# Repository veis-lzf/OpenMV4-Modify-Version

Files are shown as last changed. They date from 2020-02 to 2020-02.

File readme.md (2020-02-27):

# Open MV 4修改版

- 说明：参考自官方设计，主要修改的内容如下

	- ① PCB层数由4层板改为2层
	- ② TF卡改为了自弹式卡坐
	- ③ 摄像头连接座子改成了和OpenMV3一样的OV7725摄像头模组（感光芯片+镜头）

- 官方开源设计链接：https://github.com/openmv

- EDA设计软件：Altium Designer 20

- PCB视图

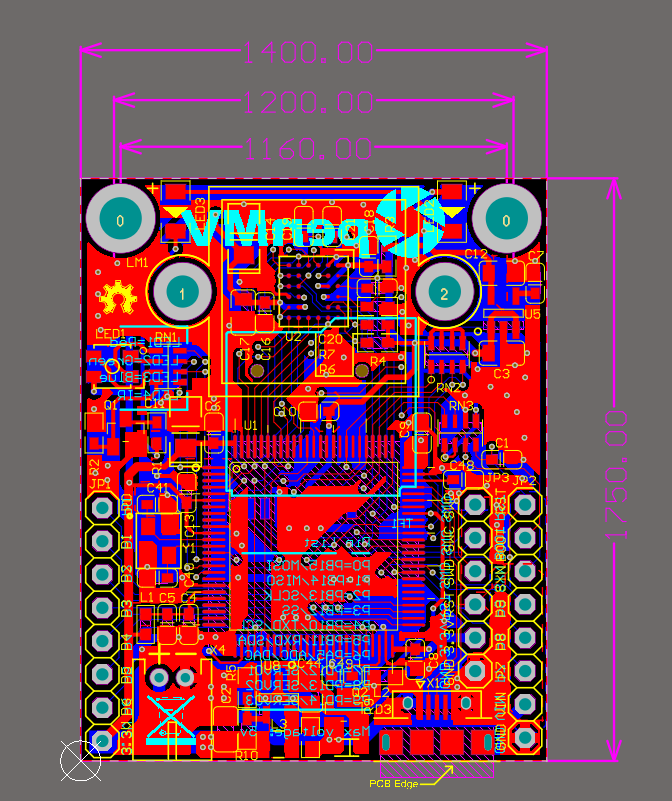
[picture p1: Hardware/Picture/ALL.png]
PCB-ALL
	

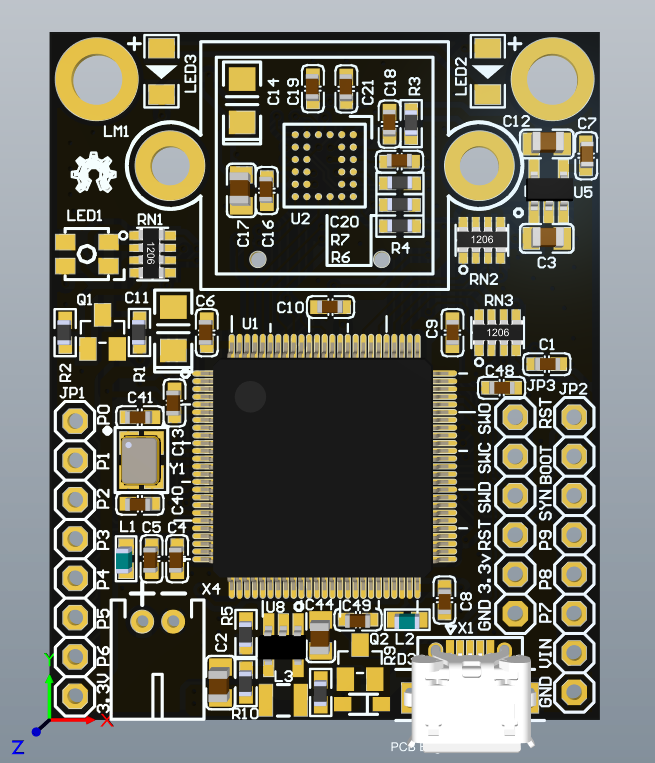
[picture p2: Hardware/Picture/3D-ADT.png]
ADT-3D
	

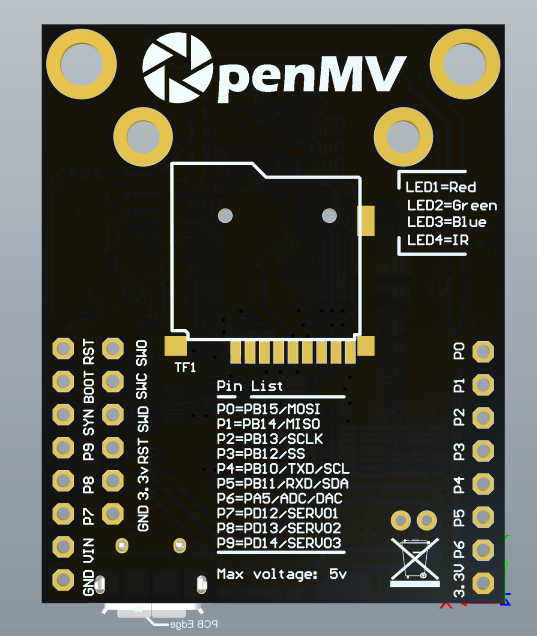
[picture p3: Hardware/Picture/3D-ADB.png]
ADB-3D


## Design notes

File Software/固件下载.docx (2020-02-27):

### 固件下载

官方固件下载： https://github.com/openmv/openmv/releases

中国服务器下载：http://openmv.cc/downloads/

参考资料：https://github.com/openmv/openmv/wiki/Using-DFU-to-update-your-firmware

DFU方式烧录固件（以OpenMV3为例）

1.安装软件

下载参考地址：https://stmicroelectronics-dfuse.updatestar.com/en

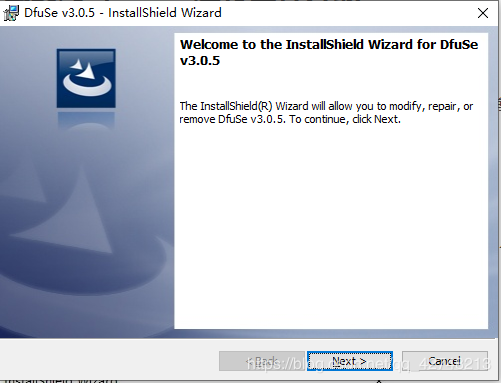
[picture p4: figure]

按照软件下一步点击即可完成软件的安装

2.进入DFU模式

用杜邦线连接Boot引脚和RST引脚。

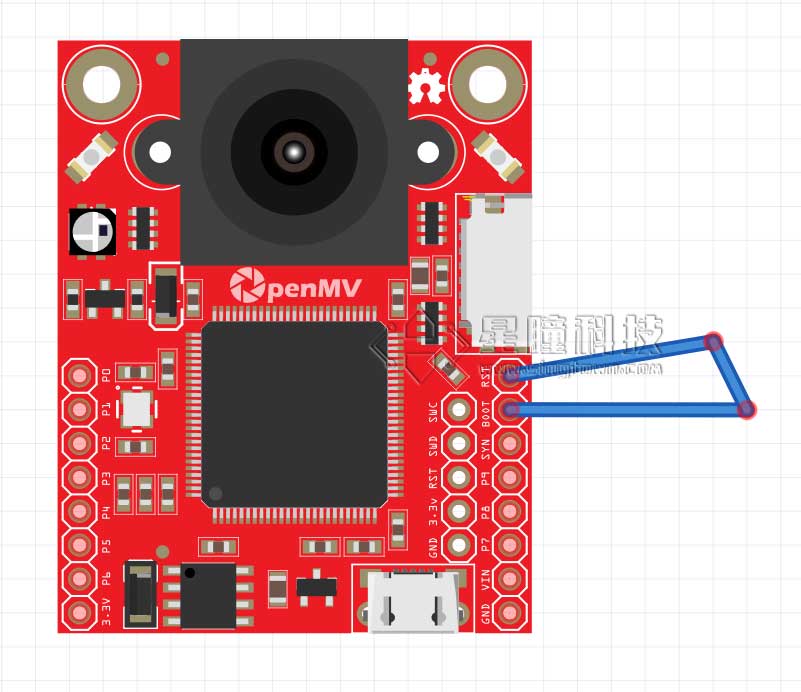
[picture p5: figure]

用USB先连接电脑后， 设备管理器会出现一个DFU设备

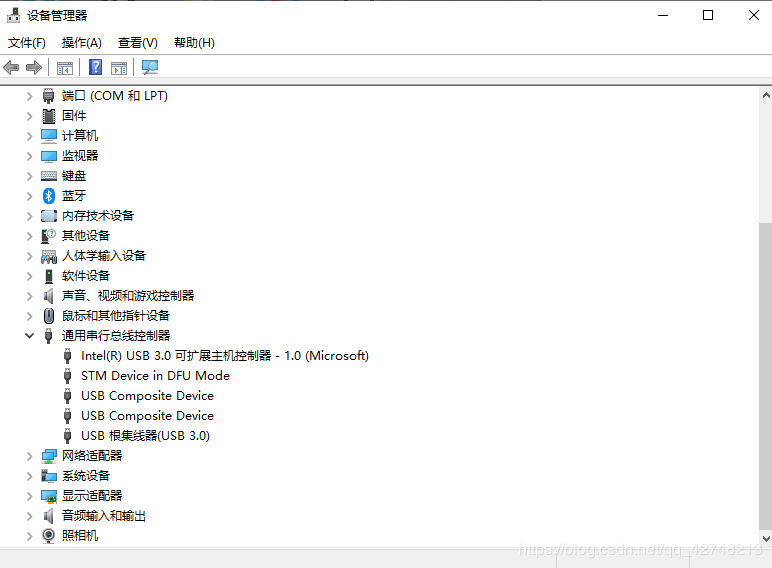
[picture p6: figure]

如果没有自动安装驱动，可以在DfuSe软件的安装路径中找到驱动文件，安装即可。

3.上传固件

打开软件，点击Choose选择openmv.dfu（不要选择左侧的Choose）

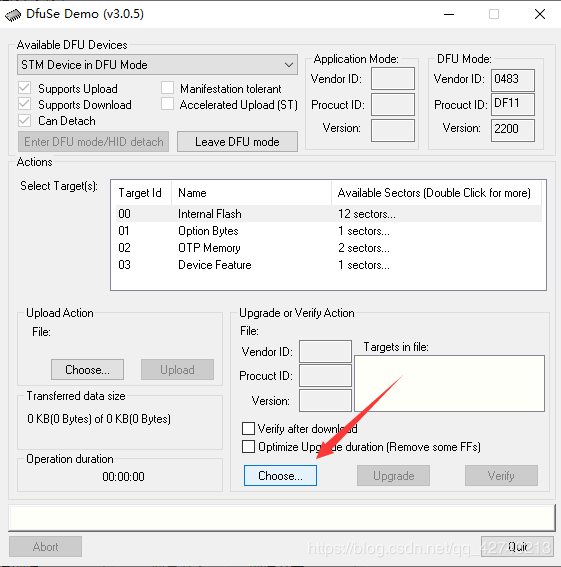
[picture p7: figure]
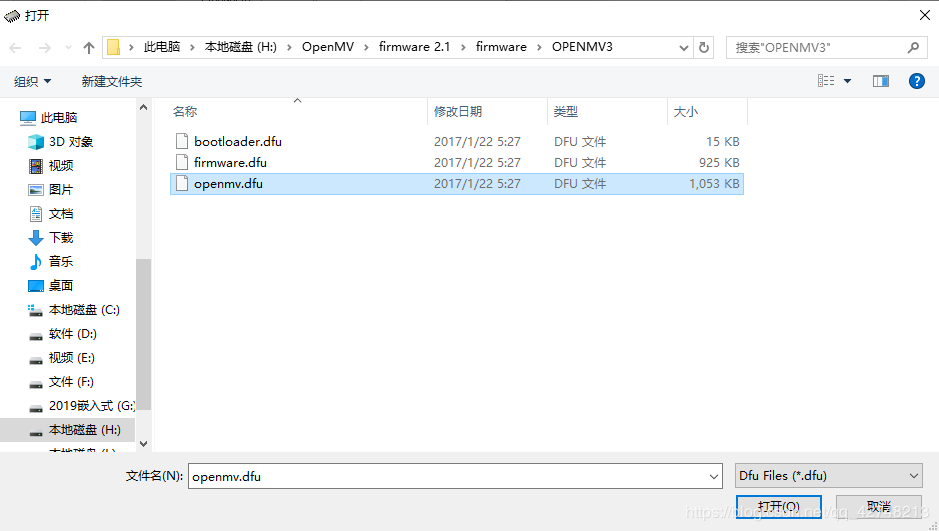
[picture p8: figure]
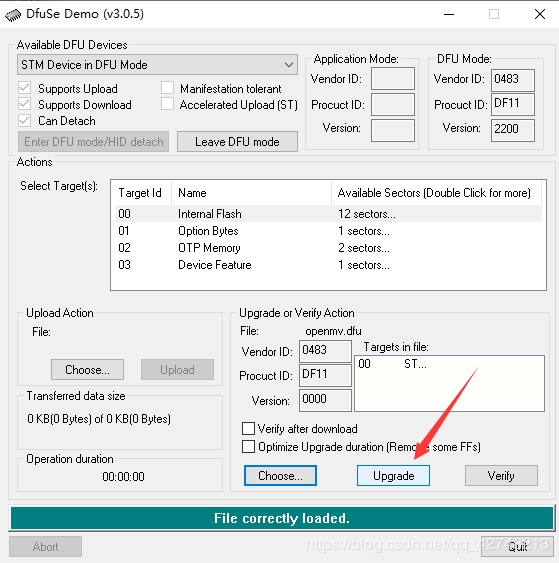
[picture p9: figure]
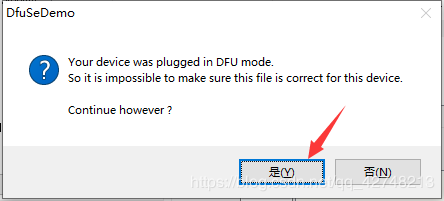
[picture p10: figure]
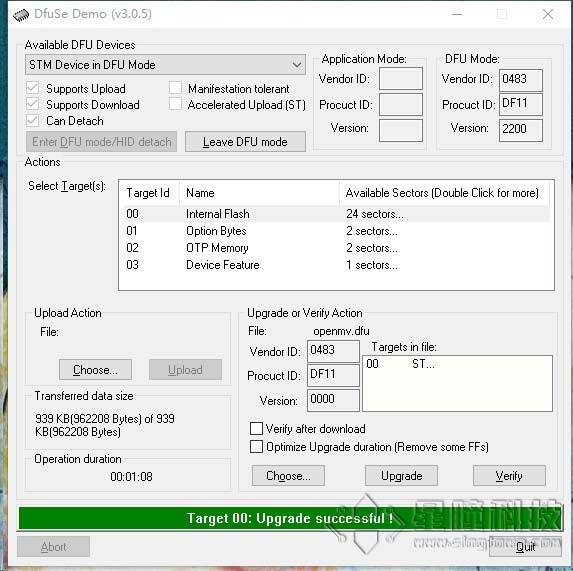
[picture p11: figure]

这样就上传成功啦。 拔下杜邦线，然后重新插上USB线，运行IDE试试吧！

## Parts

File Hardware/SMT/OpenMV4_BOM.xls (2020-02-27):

Comment | Description | Designator | Footprint | LibRef | Quantity
NC |  |  | OMV-LOGO-BIG |  | 1
NC |  |  | OSHW_FILLX100_NOTEXT |  | 1
NC |  |  | WEEE |  | 1
1uF | CapacitorStandard 0603 ceramic capacitor, and 0.1" leaded capacitor. | C1, C4 | C0603 | CAP0603-CAP | 2
22uF | CapacitorStandard 0603 ceramic capacitor, and 0.1" leaded capacitor. | C2, C17, C44 | C0805 | CAP0805 | 3
10uF | CapacitorStandard 0603 ceramic capacitor, and 0.1" leaded capacitor. | C3, C12 | C0805 | CAP0805 | 2
0.1uF | CapacitorStandard 0603 ceramic capacitor, and 0.1" leaded capacitor. | C5, C6, C7, C8, C9, C10, C13, C16, C19, C20, C21 | C0603 | CAP0603-CAP | 11
47uF | Capacitor PolarizedThese are standard SMD and PTH capacitors. Normally 10uF, 47uF, and 100uF in electrolytic and tantalum varieties. Always verify the external diameter of the through hole cap, it varies with capacity, voltage, and manufacturer. The EIA d | C11, C14 | EIA3216 | CAP_POL1206 | 2
4.7uF | CapacitorStandard 0603 ceramic capacitor, and 0.1" leaded capacitor. | C18 | C0603 | CAP0603-CAP | 1
12pF | CapacitorStandard 0603 ceramic capacitor, and 0.1" leaded capacitor. | C40, C41 | C0603 | CAP0603-CAP | 2
2.2uF | CapacitorStandard 0603 ceramic capacitor, and 0.1" leaded capacitor. | C48, C49 | C0603 | CAP0603-CAP | 2
SDM2U20SD3-7 | DiodeThese are standard reverse protection diodes and small signal diodes. SMA package can handle up to about 1A. SOD-323 can handle about 200mA. What the SOD-323 package when ordering, there are some mfgs out there that are 5-pin packages. | D3 | SOD323 | DIODESOD | 1
PINHD-1X8 | PIN HEADER | JP1, JP2 | 1X08 | PINHD-1X8 | 2
PINHD-1X6 | PIN HEADER | JP3 | 1X06 | PINHD-1X6 | 1
MPZ1608S181ATAH0 | InductorsBasic Inductor/Choke - 0603 and 1206. Footprints are not proven and vary greatly between part numbers. | L1, L2 | l0603 | INDUCTOR0603 | 2
4.7uH/1.4A | InductorsBasic Inductor/Choke - 0603 and 1206. Footprints are not proven and vary greatly between part numbers. | L3 | 1007 | INDUCTOR1007 | 1
LED-TRICOLOR | Tri-Color LED SMDProven layout and schematic for triple color LED in SMD package - common anode. Spark Fun Electronics SKU : COM-07844 | LED1 | LED-TRICOLOR-SMD-MF | LED-TRICOLOR | 1
VSMY12850 | LEDsStandard schematic elements and footprints for 5mm, 3mm, 1206, and 0603 sized LEDs. 5mm - Spark Fun Electronics SKU : COM-00529 (and others) | LED2, LED3 | LED-1206 | LED1206 | 2
LENSMOUNT20MM |  | LM1 | LENSMOUNT-20MM | LENSMOUNT20MM | 1
BSS138 |  | Q1 | SOT23-3 | MOSFET-NCHANNELSMD | 1
Si2301BDS |  | Q2 | SOT23-3 | MOSFET-PCHANNELSMD | 1
10R | ResistorBasic schematic elements and footprints for 0603, 1206, and PTH resistors. | R1 | R0603 | RESISTOR0603-RES | 1
10K | ResistorBasic schematic elements and footprints for 0603, 1206, and PTH resistors. | R2, R7, R9 | R0603 | RESISTOR0603-RES | 3
4.7K | ResistorBasic schematic elements and footprints for 0603, 1206, and PTH resistors. | R3, R4, R6 | R0603 | RESISTOR0603-RES | 3
100K | ResistorBasic schematic elements and footprints for 0603, 1206, and PTH resistors. | R5 | R0603 | RESISTOR0603-RES | 1
453K | ResistorBasic schematic elements and footprints for 0603, 1206, and PTH resistors. | R10 | R0603 | RESISTOR0603-RES | 1
220R | Array Chip Resistor Source: RS Component / Phycomp | RN1 | EXBV8V | 4R-NEXBV8V | 1
10K | Array Chip Resistor Source: RS Component / Phycomp | RN2, RN3 | EXBV8V | 4R-NEXBV8V | 2
TF_Card |  | TF1 | TF-2 | TF_CADE | 1
STM32H743VIT6 |  | U1 | LQFP100 | STM32F746LQFP100 | 1
OV7725 |  | U2 | CSP2-28 | OV7725 | 1
TPS731XX |  | U5 | SOT23-5 | TPS731XX | 1
PAM2305AABADJ |  | U8 | SOT23-5 | PAM2305AAB330 | 1
MF-CON-MICROUSB-RIGHT | Library: MF_Connectors Description: 5 Pin USB Connectors. SLD is the shield connection. Usually tied to ground through a small ferrite bead. | X1 | MICROUSB-RIGHT | USB_MICRO_RIGHT | 1
S2B-PH-K-S(LF)(SN) | JST 2-Pin Connectors of various flavors SMT-RA (S2B-PH-SM4) 4UConnector #17311 SMT (B2B-PH-SM4) THM-RA (S2B-PH) THM (B2B-PH) | X4 | JST-PH-2-THM-RA | JST_2PIN-THM-RA | 1
7S-12.000MAHE-T | CrystalsVarious standard crystals. Proven footprints. Spark Fun Electronics SKU : COM-00534 | Y1 | XTAL-SMD-3225_4P | CRYSTAL2.5X2.0 | 1

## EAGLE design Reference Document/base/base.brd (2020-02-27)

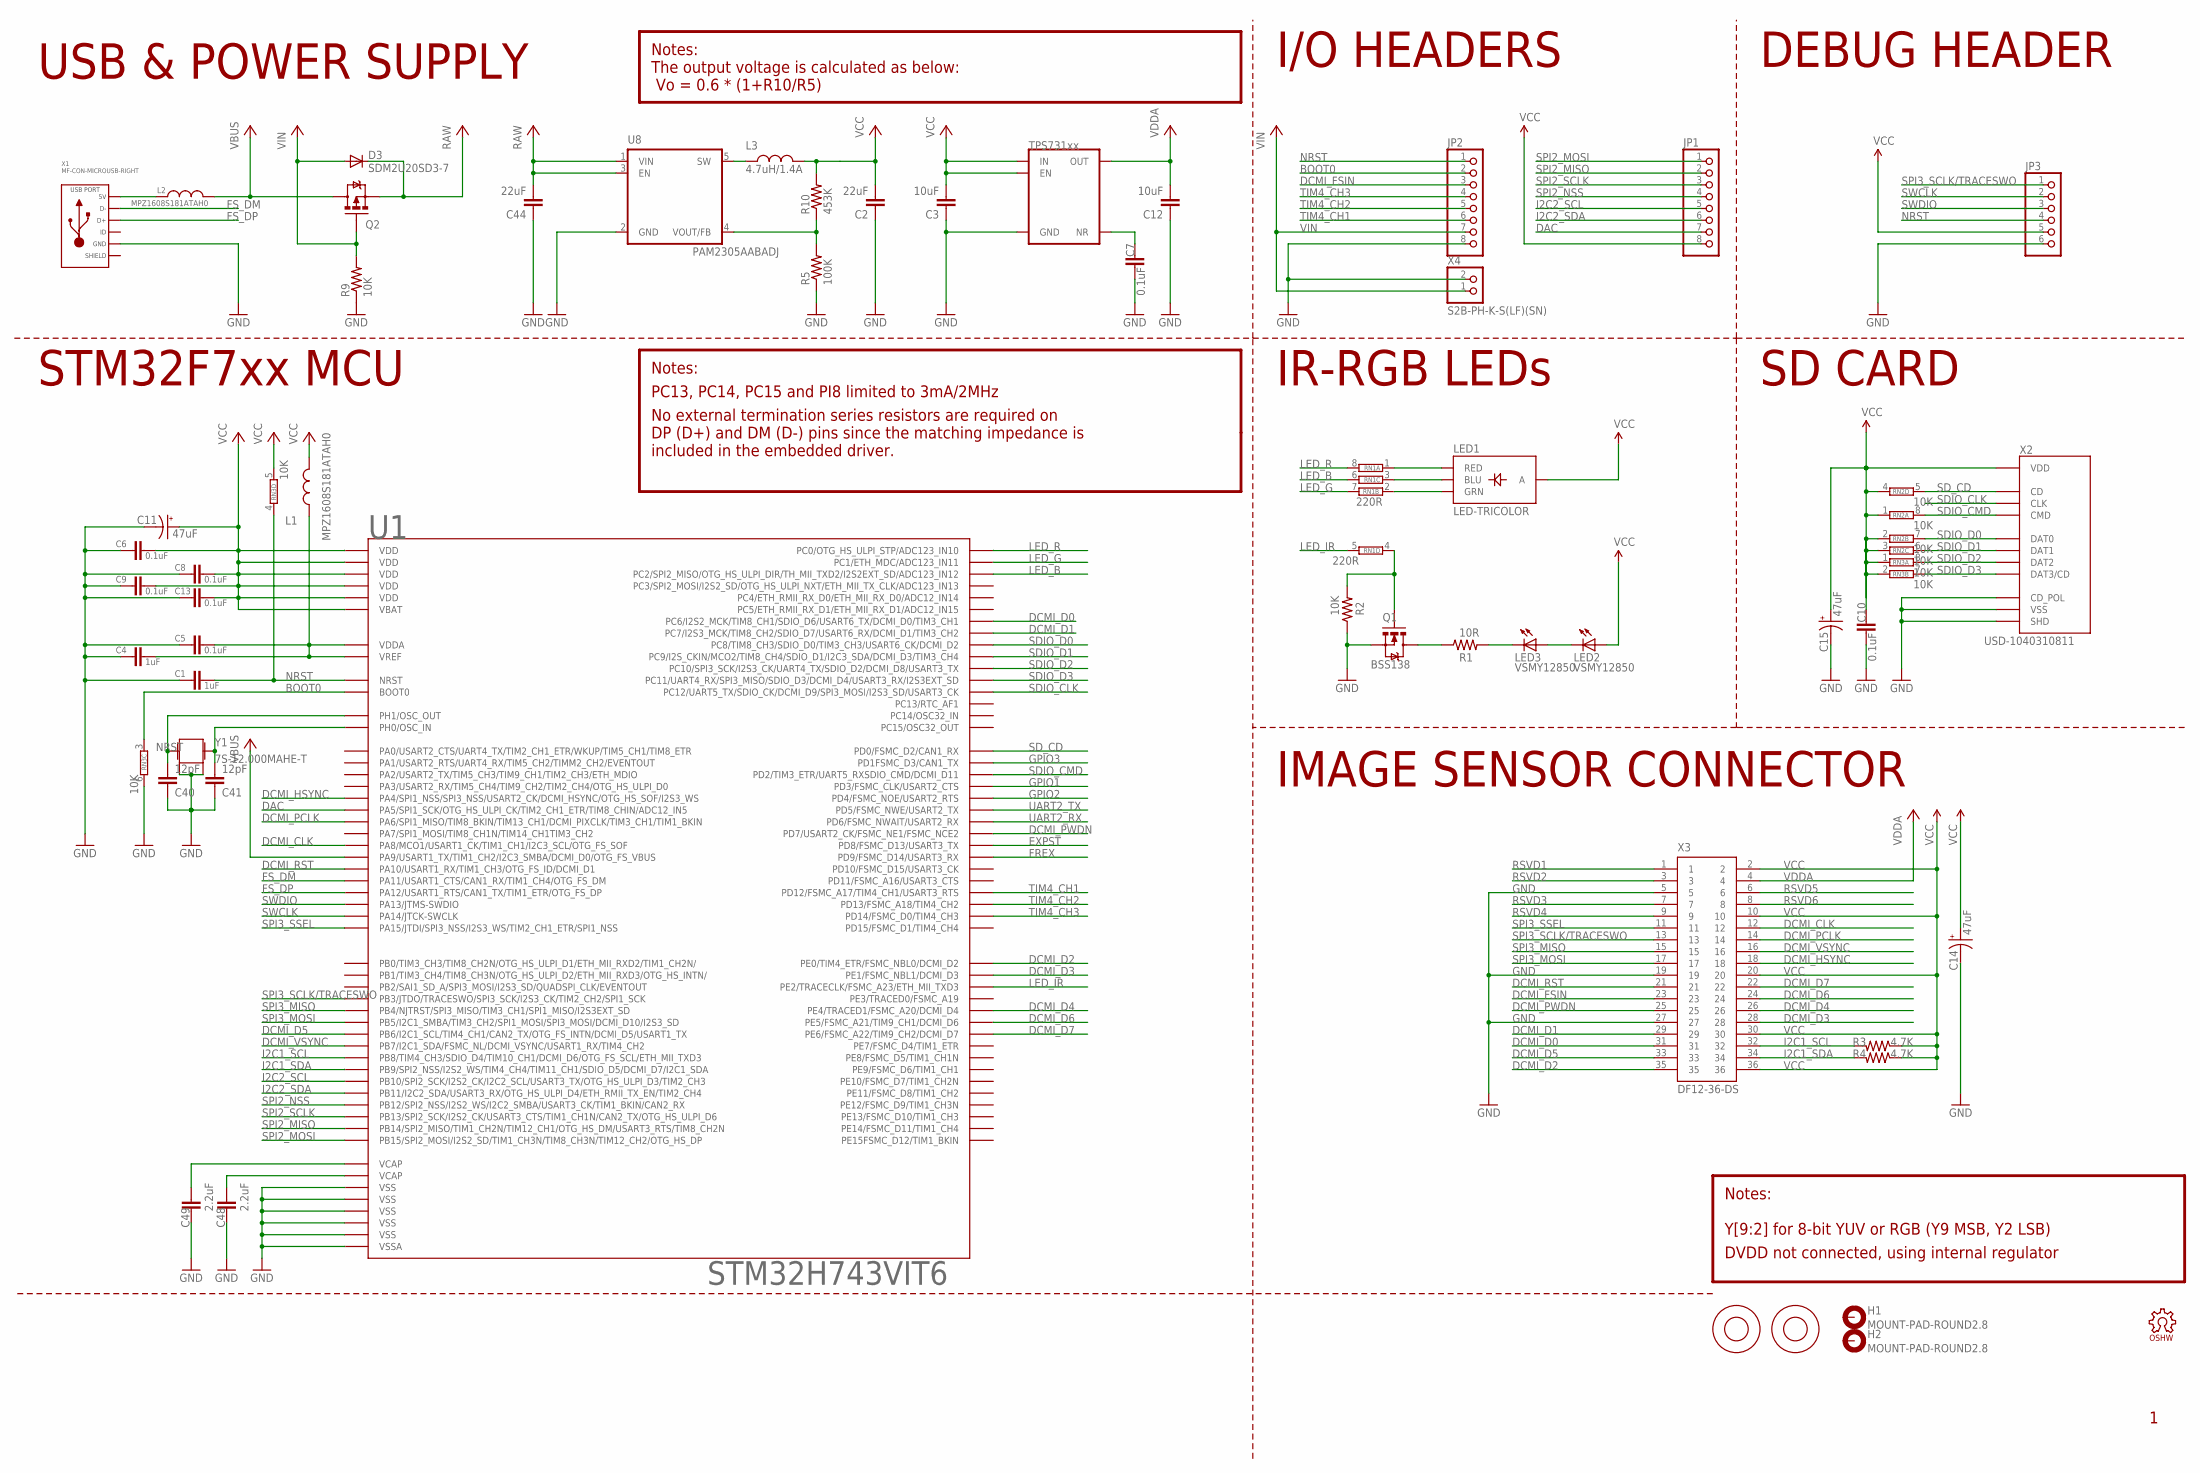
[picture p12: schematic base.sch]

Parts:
C1, C4: 1uF; 0603-CAP
C2, C44: 22uF; 0805
C3, C12: 10uF; 0805
C5, C6, C7, C8, C9, C10, C13: 0.1uF; 0603-CAP
C11, C14, C15: 47uF; EIA3216
C40, C41: 12pF; 0603-CAP
C48, C49: 2.2uF; 0603-CAP
D3: SDM2U20SD3-7; SOD-323
H1, H2: MOUNT-PAD-ROUND2.8; 2,8-PAD
JP1, JP2: PINHD-1X8; 1X08
JP3: PINHD-1X6; 1X06
L1, L2: MPZ1608S181ATAH0; 0603
L3: 4.7uH/1.4A; 1007
LED1: LED-TRICOLOR; LED-TRICOLOR-SMD-MF
LED2, LED3: VSMY12850; LED-1206
LOGO1: OSHW_LOGO_FILLX0100-NT; OSHW_FILLX100_NOTEXT
M1, M2: 9774030243R; 9774030151R
Q1: BSS138; SOT23-3
Q2: Si2301BDS; SOT23-3
R1: 10R; 0603-RES
R2, R9: 10K; 0603-RES
R3, R4: 4.7K; 0603-RES
R5: 100K; 0603-RES
R10: 453K; 0603-RES
RN1: 220R; EXBV8V
RN2, RN3: 10K; EXBV8V
U1: STM32H743VIT6; LQFP100
U5: TPS731XX; SOT23-5
U8: PAM2305AABADJ; TSOT25
X1: MF-CON-MICROUSB-RIGHT; MICROUSB-RIGHT
X2: USD-1040310811; 1040310811
X3: DF12-36-DS
X4: S2B-PH-K-S(LF)(SN); JST-PH-2-THM-RA
Y1: 7S-12.000MAHE-T; CRYSTAL-2.5X2.0

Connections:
BOOT0: JP2.2, RN3.3 (1), U1.94 (BOOT0)
DAC: JP1.7, U1.29 (PA5/SPI1_SCK/OTG_HS_ULPI_CK/TIM2_CH1_ET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)
DCMI_CLK: U1.67 (PA8/MCO1/USART1_CK/TIM1_CH1/I2C3_SCL/OT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), X3.12
DCMI_D0: U1.63 (PC6/I2S2_MCK/TIM8_CH1/SDIO_D6/USART6_TX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), X3.31
DCMI_D1: U1.64 (PC7/I2S3_MCK/TIM8_CH2/SDIO_D7/USART6_RX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), X3.29
DCMI_D2: U1.97 (PE0/TIM4_ETR/FSMC_NBL0/DCMI_D2), X3.35
DCMI_D3: U1.98 (PE1/FSMC_NBL1/DCMI_D3), X3.28
DCMI_D4: U1.3 (PE4/TRACED1/FSMC_A20/DCMI_D4), X3.26
DCMI_D5: U1.92 (PB6/I2C1_SCL/TIM4_CH1/CAN2_TX/OTG_FS_IN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), X3.33
DCMI_D6: U1.4 (PE5/FSMC_A21/TIM9_CH1/DCMI_D6), X3.24
DCMI_D7: U1.5 (PE6/FSMC_A22/TIM9_CH2/DCMI_D7), X3.22
DCMI_FSIN: JP2.3, X3.23
DCMI_HSYNC: U1.28 (PA4/SPI1_NSS/SPI3_NSS/USART2_CK/DCMI_HS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), X3.18
DCMI_PCLK: U1.30 (PA6/SPI1_MISO/TIM8_BKIN/TIM13_CH1/DCMI_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), X3.14
DCMI_PWDN: U1.88 (PD7/USART2_CK/FSMC_NE1/FSMC_NCE2), X3.25
DCMI_RST: U1.69 (PA10/USART1_RX/TIM1_CH3/OTG_FS_ID/DCMI_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), X3.21
DCMI_VSYNC: U1.93 (PB7/I2C1_SDA/FSMC_NL/DCMI_VSYNC/USART1_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), X3.16
EXPST: U1.55 (PD8/FSMC_D13/USART3_TX)
FREX: U1.56 (PD9/FSMC_D14/USART3_RX)
FS_DM: U1.70 (PA11/USART1_CTS/CAN1_RX/TIM1_CH4/OTG_FS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), X1.2 (D-)
FS_DP: U1.71 (PA12/USART1_RTS/CAN1_TX/TIM1_ETR/OTG_FS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), X1.3 (D+)
GND: C1.2, C2.1, C3.1, C4.2, C5.2, C6.2, C7.2, C8.2, C9.2, C10.2, C11.C (-), C12.1, C13.2, C14.C (-), C15.C (-), C40.1, C41.1, C44.1, C48.2, C49.2, JP2.8, JP3.6, Q1.2 (S), R2.1, R5.1, R9.1, RN3.6 (2), U1.10 (VSS), U1.19 (VSSA), U1.26 (VSS), U1.49 (VSS), U1.74 (VSS), U1.99 (VSS), U5.2 (GND), U8.2 (GND), X1.5 (GND), X2.CD$2 (CD_POL), X2.G$1 (SHD), X2.G$2 (SHD), X2.G$3 (SHD), X2.G$4 (SHD), X2.P$6 (VSS), X3.5, X3.19, X3.27, X4.2 (1), Y1.2, Y1.4
GPIO1: U1.84 (PD3/FSMC_CLK/USART2_CTS)
GPIO2: U1.85 (PD4/FSMC_NOE/USART2_RTS)
GPIO3: U1.82 (PD1FSMC_D3/CAN1_TX)
I2C1_SCL: R3.2, U1.95 (PB8/TIM4_CH3/SDIO_D4/TIM10_CH1/DCMI_D6/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), X3.32
I2C1_SDA: R4.2, U1.96 (PB9/SPI2_NSS/I2S2_WS/TIM4_CH4/TIM11_CH1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), X3.34
I2C2_SCL: JP1.5, U1.46 (PB10/SPI2_SCK/I2S2_CK/I2C2_SCL/USART3_T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)
I2C2_SDA: JP1.6, U1.47 (PB11/I2C2_SDA/USART3_RX/OTG_HS_ULPI_D4/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)
LED_B: RN1.6 (2), U1.17 (PC2/SPI2_MISO/OTG_HS_ULPI_DIR/TH_MII_TX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)
LED_G: RN1.7 (2), U1.16 (PC1/ETH_MDC/ADC123_IN11)
LED_IR: RN1.5 (2), U1.1 (PE2/TRACECLK/FSMC_A23/ETH_MII_TXD3)
LED_R: RN1.8 (2), U1.15 (PC0/OTG_HS_ULPI_STP/ADC123_IN10)
unnamed: C40.2, U1.13 (PH1/OSC_OUT), Y1.3 (2)
unnamed: C41.2, U1.12 (PH0/OSC_IN), Y1.1
unnamed: Q1.1 (G), R2.2, RN1.4 (1)
unnamed: LED1.B (BLU), RN1.3 (1)
unnamed: L2.1, X1.1 (5V)
unnamed: LED1.R (RED), RN1.1
unnamed: LED1.G (GRN), RN1.2 (1)
unnamed: LED3.C, R1.2
unnamed: C7.1, U5.4 (NR)
unnamed: C4.1, C5.1, L1.1, U1.20 (VREF), U1.21 (VDDA)
unnamed: R5.2, R10.1, U8.4 (VOUT/FB)
unnamed: Q1.3 (D), R1.1
unnamed: LED2.C, LED3.A
NRST: C1.1, JP2.1, JP3.4, RN3.4 (1), U1.14 (NRST)
RAW: C44.2, D3.1 (C), Q2.2 (S), U8.1 (VIN), U8.3 (EN)
RSVD1: X3.1
RSVD2: X3.3
RSVD3: X3.7
RSVD4: X3.9
RSVD5: X3.6
RSVD6: X3.8
SDIO_CLK: U1.80 (PC12/UART5_TX/SDIO_CK/DCMI_D9/SPI3_MOSI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), X2.P$5 (CLK)
SDIO_CMD: RN2.8 (2), U1.83 (PD2/TIM3_ETR/UART5_RXSDIO_CMD/DCMI_D11), X2.P$3 (CMD)
SDIO_D0: RN2.7 (2), U1.65 (PC8/TIM8_CH3/SDIO_D0/TIM3_CH3/USART6_CK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), X2.P$7 (DAT0)
SDIO_D1: RN2.6 (2), U1.66 (PC9/I2S_CKIN/MCO2/TIM8_CH4/SDIO_D1/I2C3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), X2.P$8 (DAT1)
SDIO_D2: RN3.8 (2), U1.78 (PC10/SPI3_SCK/I2S3_CK/UART4_TX/SDIO_D2/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), X2.P$1 (DAT2)
SDIO_D3: RN3.7 (2), U1.79 (PC11/UART4_RX/SPI3_MISO/SDIO_D3/DCMI_D4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), X2.P$2 (DAT3/CD)
SD_CD: RN2.5 (2), U1.81 (PD0/FSMC_D2/CAN1_RX), X2.CD$1 (CD)
SPI2_MISO: JP1.2, U1.53 (PB14/SPI2_MISO/TIM1_CH2N/TIM12_CH1/OTG_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)
SPI2_MOSI: JP1.1, U1.54 (PB15/SPI2_MOSI/I2S2_SD/TIM1_CH3N/TIM8_C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)
SPI2_NSS: JP1.4, U1.51 (PB12/SPI2_NSS/I2S2_WS/I2C2_SMBA/USART3_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)
SPI2_SCLK: JP1.3, U1.52 (PB13/SPI2_SCK/I2S2_CK/USART3_CTS/TIM1_C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)
SPI3_MISO: U1.90 (PB4/NJTRST/SPI3_MISO/TIM3_CH1/SPI1_MISO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), X3.15
SPI3_MOSI: U1.91 (PB5/I2C1_SMBA/TIM3_CH2/SPI1_MOSI/SPI3_M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), X3.17
SPI3_SCLK/TRACESWO: JP3.1, U1.89 (PB3/JTDO/TRACESWO/SPI3_SCK/I2S3_CK/TIM2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), X3.13
SPI3_SSEL: U1.77 (PA15/JTDI/SPI3_NSS/I2S3_WS/TIM2_CH1_ETR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), X3.11
SW: L3.1, U8.5 (SW)
SWCLK: JP3.2, U1.76 (PA14/JTCK-SWCLK)
SWDIO: JP3.3, U1.72 (PA13/JTMS-SWDIO)
TIM4_CH1: JP2.6, U1.59 (PD12/FSMC_A17/TIM4_CH1/USART3_RTS)
TIM4_CH2: JP2.5, U1.60 (PD13/FSMC_A18/TIM4_CH2)
TIM4_CH3: JP2.4, U1.61 (PD14/FSMC_D0/TIM4_CH3)
UART2_RX: U1.87 (PD6/FSMC_NWAIT/USART2_RX)
UART2_TX: U1.86 (PD5/FSMC_NWE/USART2_TX)
VBUS: L2.2, Q2.3 (D), U1.68 (PA9/USART1_TX/TIM1_CH2/I2C3_SMBA/DCMI_D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)
VCAP1: C49.1, U1.48 (VCAP)
VCAP2: C48.1, U1.73 (VCAP)
VCC: C2.2, C3.2, C6.1, C8.1, C9.1, C10.1, C11.A (+), C13.1, C14.A (+), C15.A (+), JP1.8, JP3.5, L1.2, L3.2, LED1.A, LED2.A, R3.1, R4.1, R10.2, RN2.1, RN2.2 (1), RN2.3 (1), RN2.4 (1), RN3.1, RN3.2 (1), RN3.5 (2), U1.6 (VBAT), U1.11 (VDD), U1.27 (VDD), U1.50 (VDD), U1.75 (VDD), U1.100 (VDD), U5.1 (IN), U5.3 (EN), X2.P$4 (VDD), X3.2, X3.10, X3.20, X3.30, X3.36
VDDA: C12.2, U5.5 (OUT), X3.4
VIN: D3.2 (A), JP2.7, Q2.1 (G), R9.2, X4.1 (2)

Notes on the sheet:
PC13, PC14, PC15 and PI8 limited to 3mA/2MHz
SD CARD
Y[9:2] for 8-bit YUV or RGB (Y9 MSB, Y2 LSB)
DVDD not connected, using internal regulator
Notes:
IMAGE SENSOR CONNECTOR
STM32F7xx MCU
IR-RGB LEDs
USB & POWER SUPPLY
DEBUG HEADER
I/O HEADERS
No external termination series resistors are required on DP (D+) and DM (D-) pins since the matching impedance is included in the embedded driver.
The output voltage is calculated as below: Vo = 0.6 * (1+R10/R5)

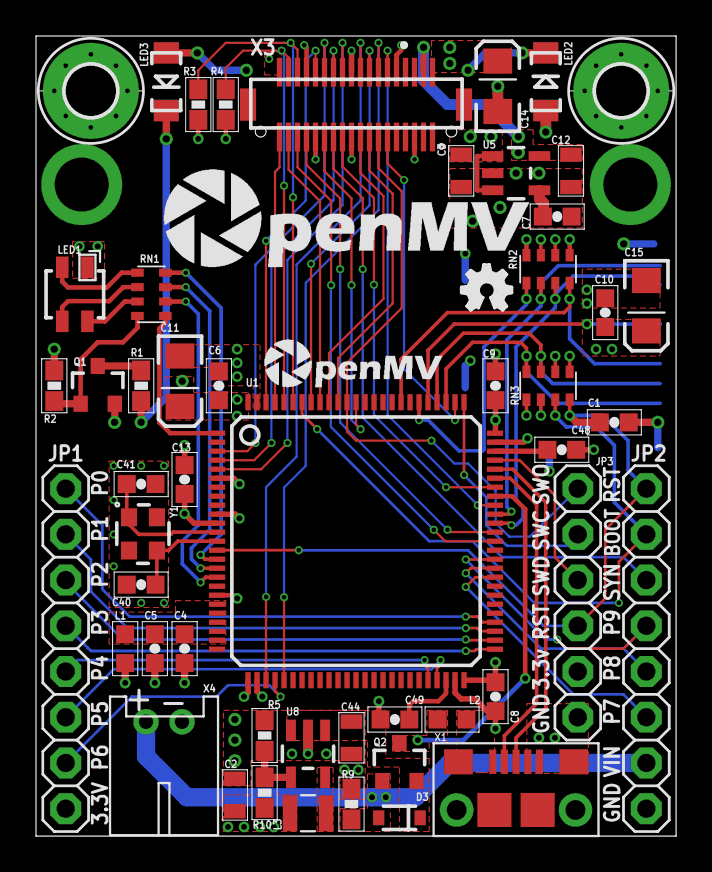
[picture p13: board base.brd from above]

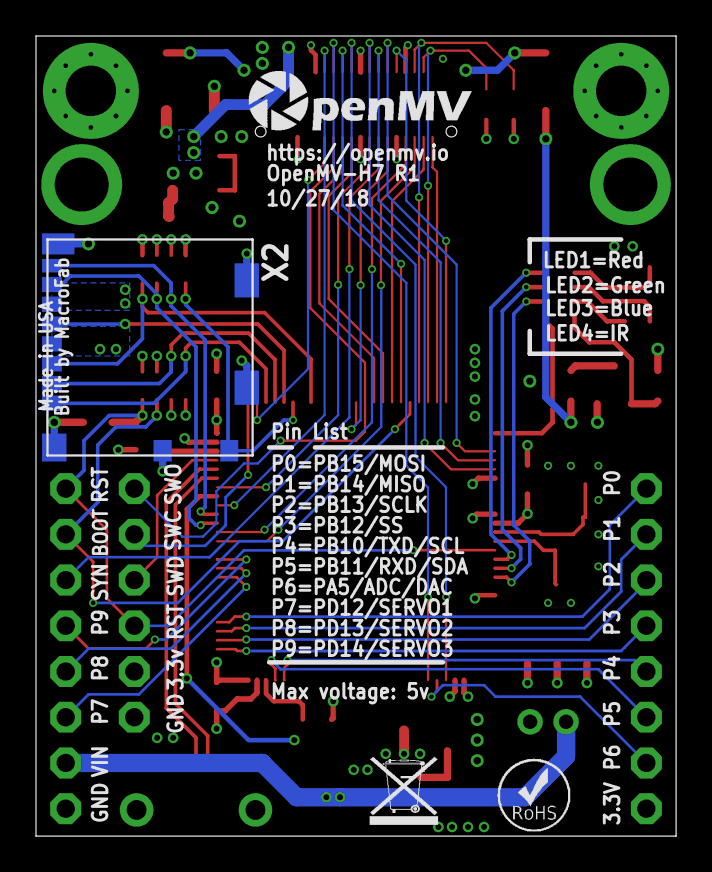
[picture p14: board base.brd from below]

Board: 4 copper layers, 35.6 x 44.5 mm, 60 parts (4 on the bottom side), 70 nets.

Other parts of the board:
U$1: WEEE
U$2: ROHS
U$3: OMV-LOGO
U$4: OMV-LOGO-SMALL
U$6: OMV-LOGO-BIG

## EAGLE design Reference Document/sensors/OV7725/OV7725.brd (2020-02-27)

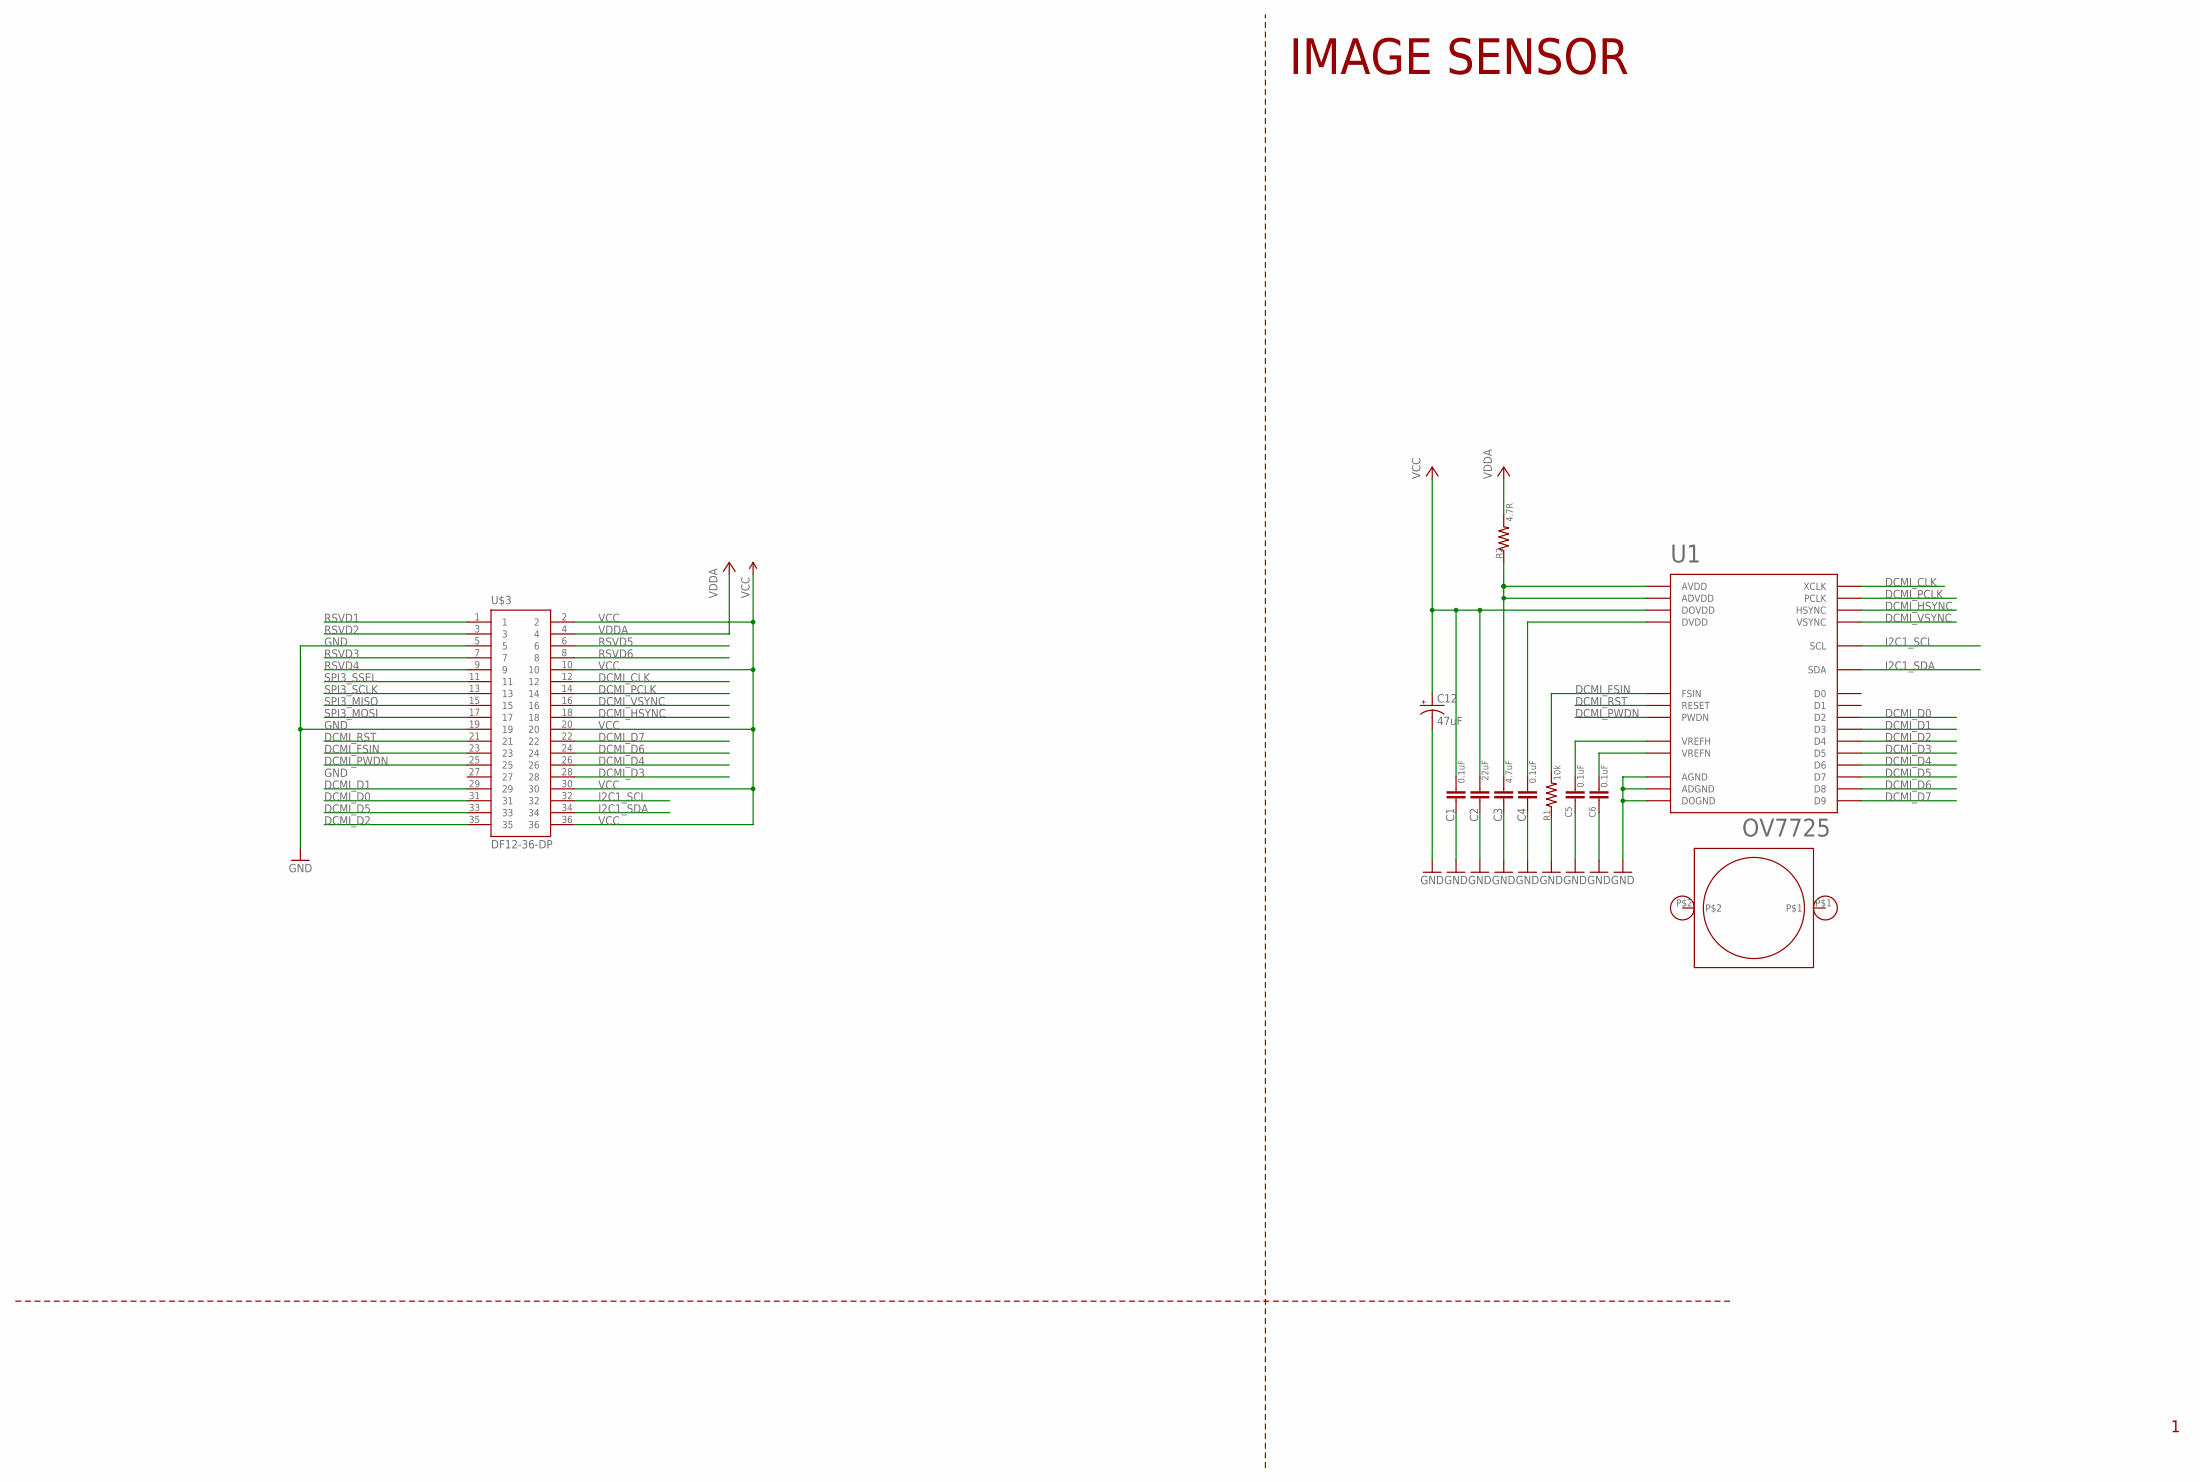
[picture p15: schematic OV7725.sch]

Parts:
C1, C4, C5, C6: 0.1uF; 0603-CAP
C2: 22uF; 0805
C3: 4.7uF; 0603-CAP
C12: 47uF; EIA3216
LM1: LENSMOUNT20MM; LENSMOUNT-20MM
R1: 10k; 0603-RES
R2: 4.7R; 0603-RES
U1: OV7725; CSP2-28
U$3: DF12-36-DP

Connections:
AVDD: C3.1, R2.1, U1.A1 (ADVDD), U1.B3 (AVDD)
DCMI_CLK: U1.F3 (XCLK), U$3.12
DCMI_D0: U1.F5 (D2), U$3.31
DCMI_D1: U1.F2 (D3), U$3.29
DCMI_D2: U1.D6 (D4), U$3.35
DCMI_D3: U1.D1 (D5), U$3.28
DCMI_D4: U1.E6 (D6), U$3.26
DCMI_D5: U1.E1 (D7), U$3.33
DCMI_D6: U1.F6 (D8), U$3.24
DCMI_D7: U1.F1 (D9), U$3.22
DCMI_FSIN: R1.2, U1.A4 (FSIN), U$3.23
DCMI_HSYNC: U1.B6 (HSYNC), U$3.18
DCMI_PCLK: U1.E4 (PCLK), U$3.14
DCMI_PWDN: U1.C1 (PWDN), U$3.25
DCMI_RST: U1.A2 (RESET), U$3.21
DCMI_VSYNC: U1.C6 (VSYNC), U$3.16
GND: C1.2, C2.2, C3.2, C4.2, C5.2, C6.2, C12.C (-), R1.1, U1.B1 (ADGND), U1.B4 (AGND), U1.F4 (DOGND), U$3.5, U$3.19
I2C1_SCL: U1.A5 (SCL), U$3.32
I2C1_SDA: U1.B5 (SDA), U$3.34
unnamed: C5.1, U1.A3 (VREFH)
unnamed: C6.1, U1.B2 (VREFN)
unnamed: C4.1, U1.E3 (DVDD)
RSVD1: U$3.1
RSVD2: U$3.3
RSVD3: U$3.7
RSVD4: U$3.9
RSVD5: U$3.6
RSVD6: U$3.8
SPI3_MISO: U$3.15
SPI3_MOSI: U$3.17
SPI3_SCLK: U$3.13
SPI3_SSEL: U$3.11
VCC: C1.1, C2.1, C12.A (+), U1.E5 (DOVDD), U$3.2, U$3.10, U$3.20, U$3.30, U$3.36
VDDA: R2.2, U$3.4

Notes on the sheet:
IMAGE SENSOR

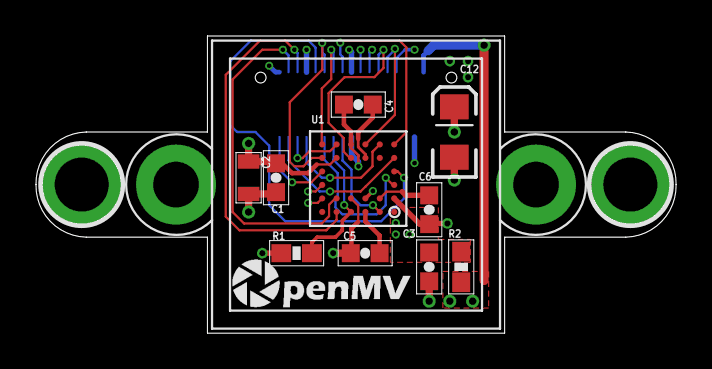
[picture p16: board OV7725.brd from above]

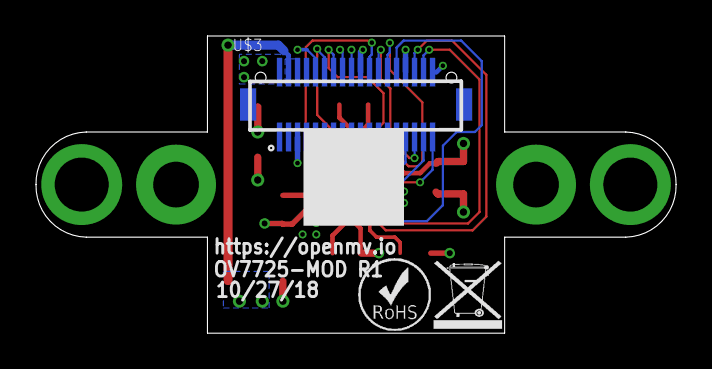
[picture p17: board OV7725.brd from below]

Board: 4 copper layers, 35.6 x 16.5 mm, 15 parts (3 on the bottom side), 24 nets.

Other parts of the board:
U$1: WEEE
U$2: ROHS
U$4: OMV-LOGO-SMALL

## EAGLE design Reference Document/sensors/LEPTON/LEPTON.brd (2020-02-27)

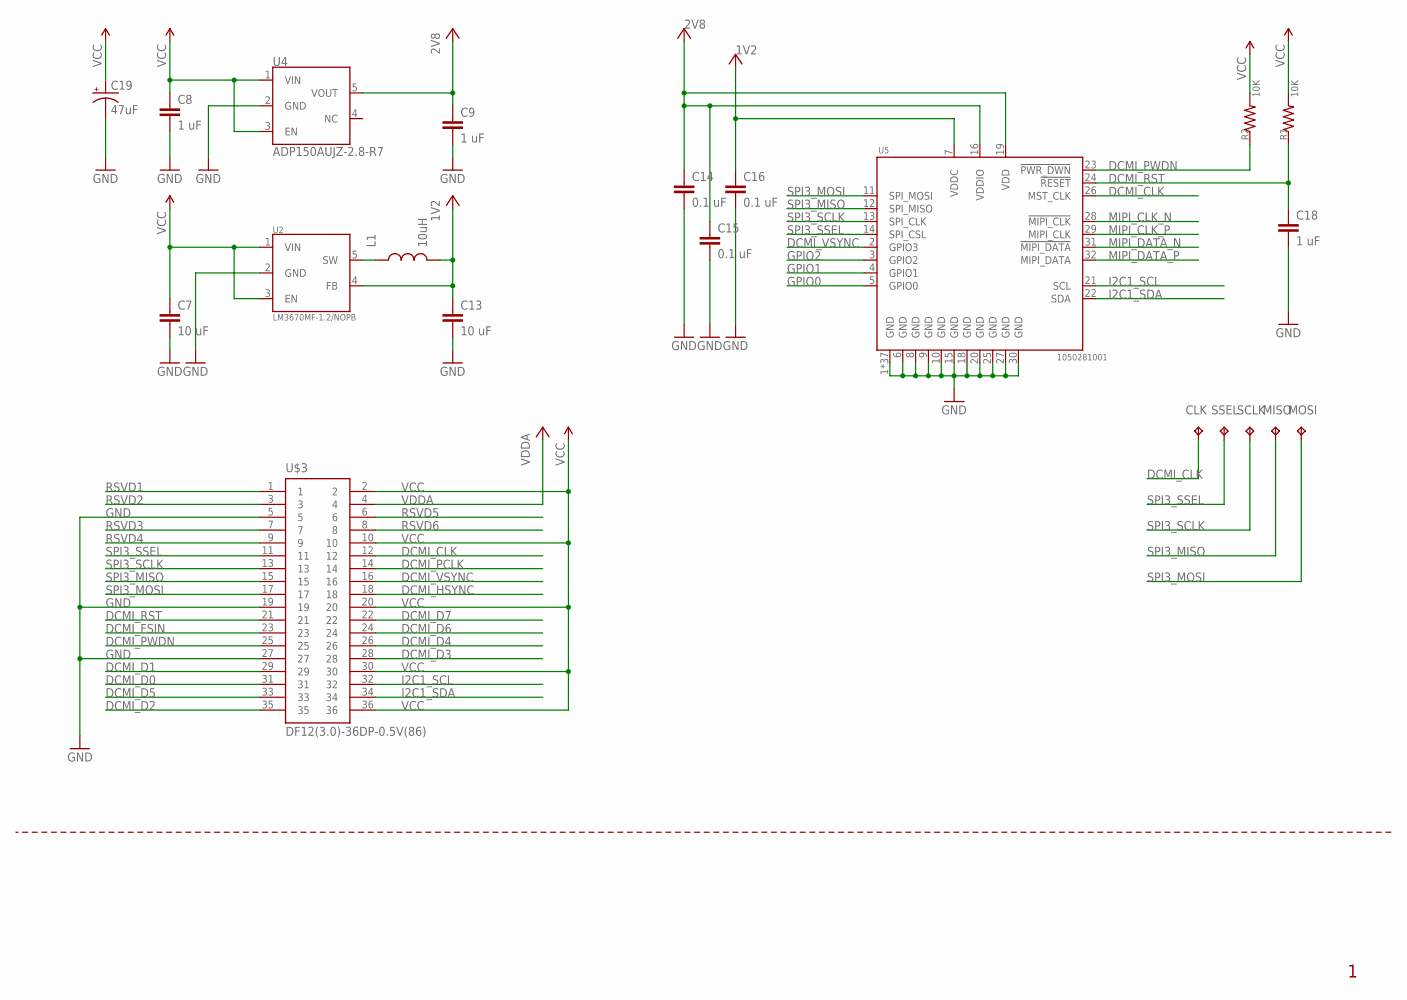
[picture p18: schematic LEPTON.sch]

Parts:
C7, C13: 10 uF; 0805
C8, C9, C18: 1 uF; 0402-CAP
C14, C15, C16: 0.1 uF; 0402-CAP
C19: 47uF; EIA3216
CLK: TPTP16R; TP16R
L1: 10uH; 1210
MISO: TPTP16R; TP16R
MOSI: TPTP16R; TP16R
R1, R2: 10K; 0402-RES
SCLK: TPTP16R; TP16R
SSEL: TPTP16R; TP16R
U2: LM3670MF-1.2/NOPB; SOT23-5
U4: ADP150AUJZ-2.8-R7; SOT23-5
U5: 1050281001; CAM-SOCKET
U$3: DF12(3.0)-36DP-0.5V(86); DF12-36-DP

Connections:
1V2: C13.1, C16.1, L1.2, U2.4 (FB), U5.7 (VDDC)
2V8: C9.1, C14.1, C15.1, U4.5 (VOUT), U5.16 (VDDIO), U5.19 (VDD)
DCMI_CLK: CLK.TP, U5.26 (MST_CLK), U$3.12
DCMI_D0: U$3.31
DCMI_D1: U$3.29
DCMI_D2: U$3.35
DCMI_D3: U$3.28
DCMI_D4: U$3.26
DCMI_D5: U$3.33
DCMI_D6: U$3.24
DCMI_D7: U$3.22
DCMI_FSIN: U$3.23
DCMI_HSYNC: U$3.18
DCMI_PCLK: U$3.14
DCMI_PWDN: R2.1, U5.23 (!PWR_DWN), U$3.25
DCMI_RST: C18.1, R1.1, U5.24 (!RESET), U$3.21
DCMI_VSYNC: U5.2 (GPIO3), U$3.16
GND: C7.2, C8.2, C9.2, C13.2, C14.2, C15.2, C16.2, C18.2, C19.C (-), U2.2 (GND), U4.2 (GND), U5.1 (GND), U5.6 (GND), U5.8 (GND), U5.9 (GND), U5.10 (GND), U5.15 (GND), U5.18 (GND), U5.20 (GND), U5.25 (GND), U5.27 (GND), U5.30 (GND), U5.P$1 (GND), U5.P$2 (GND), U5.P$3 (GND), U5.P$4 (GND), U5.P$5 (GND), U5.P$6 (GND), U5.P$7 (GND), U5.P$8 (GND), U5.P$9 (GND), U5.P$10 (GND), U5.P$11 (GND), U5.P$12 (GND), U5.P$13 (GND), U5.P$14 (GND), U5.P$15 (GND), U5.P$16 (GND), U5.P$17 (GND), U5.P$18 (GND), U5.P$19 (GND), U5.P$20 (GND), U5.P$21 (GND), U5.P$22 (GND), U5.P$23 (GND), U5.P$24 (GND), U5.P$25 (GND), U5.P$26 (GND), U5.P$27 (GND), U5.P$28 (GND), U5.P$29 (GND), U5.P$30 (GND), U5.P$31 (GND), U5.P$32 (GND), U5.P$33 (GND), U5.P$34 (GND), U5.P$35 (GND), U5.P$36 (GND), U$3.5, U$3.19, U$3.27
GPIO0: U5.5 (GPIO0)
GPIO1: U5.4 (GPIO1)
GPIO2: U5.3 (GPIO2)
I2C1_SCL: U5.21 (SCL), U$3.32
I2C1_SDA: U5.22 (SDA), U$3.34
MIPI_CLK_N: U5.28 (!MIPI_CLK)
MIPI_CLK_P: U5.29 (MIPI_CLK)
MIPI_DATA_N: U5.31 (!MIPI_DATA)
MIPI_DATA_P: U5.32 (MIPI_DATA)
unnamed: L1.1, U2.5 (SW)
RSVD1: U$3.1
RSVD2: U$3.3
RSVD3: U$3.7
RSVD4: U$3.9
RSVD5: U$3.6
RSVD6: U$3.8
SPI3_MISO: MISO.TP, U5.12 (SPI_MISO), U$3.15
SPI3_MOSI: MOSI.TP, U5.11 (SPI_MOSI), U$3.17
SPI3_SCLK: SCLK.TP, U5.13 (SPI_CLK), U$3.13
SPI3_SSEL: SSEL.TP, U5.14 (SPI_CSL), U$3.11
VCC: C7.1, C8.1, C19.A (+), R1.2, R2.2, U2.1 (VIN), U2.3 (EN), U4.1 (VIN), U4.3 (EN), U$3.2, U$3.10, U$3.20, U$3.30, U$3.36
VDDA: U$3.4

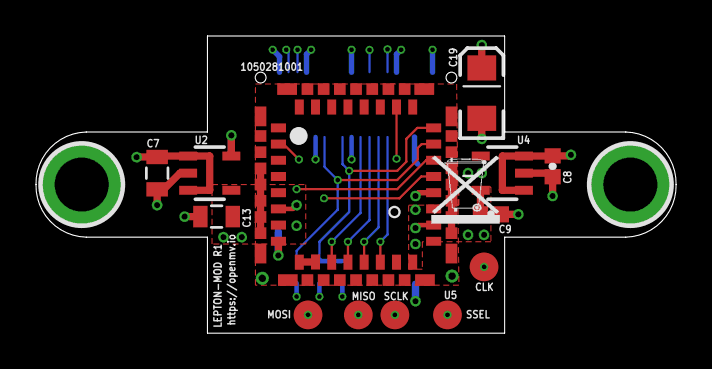
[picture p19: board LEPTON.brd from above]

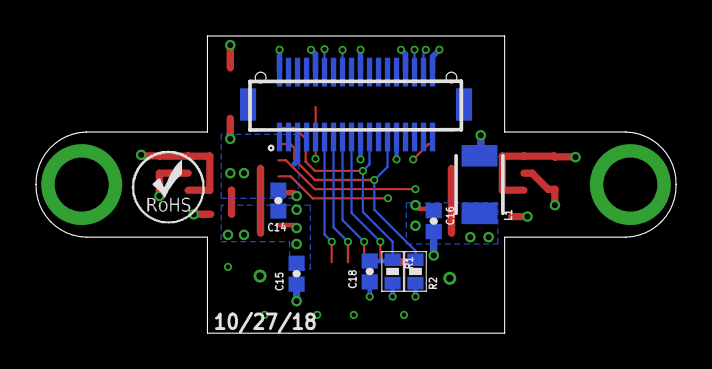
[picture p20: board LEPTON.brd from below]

Board: 4 copper layers, 35.6 x 16.5 mm, 23 parts (9 on the bottom side), 15 nets.

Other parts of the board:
U$4: WEEE
U$5: ROHS

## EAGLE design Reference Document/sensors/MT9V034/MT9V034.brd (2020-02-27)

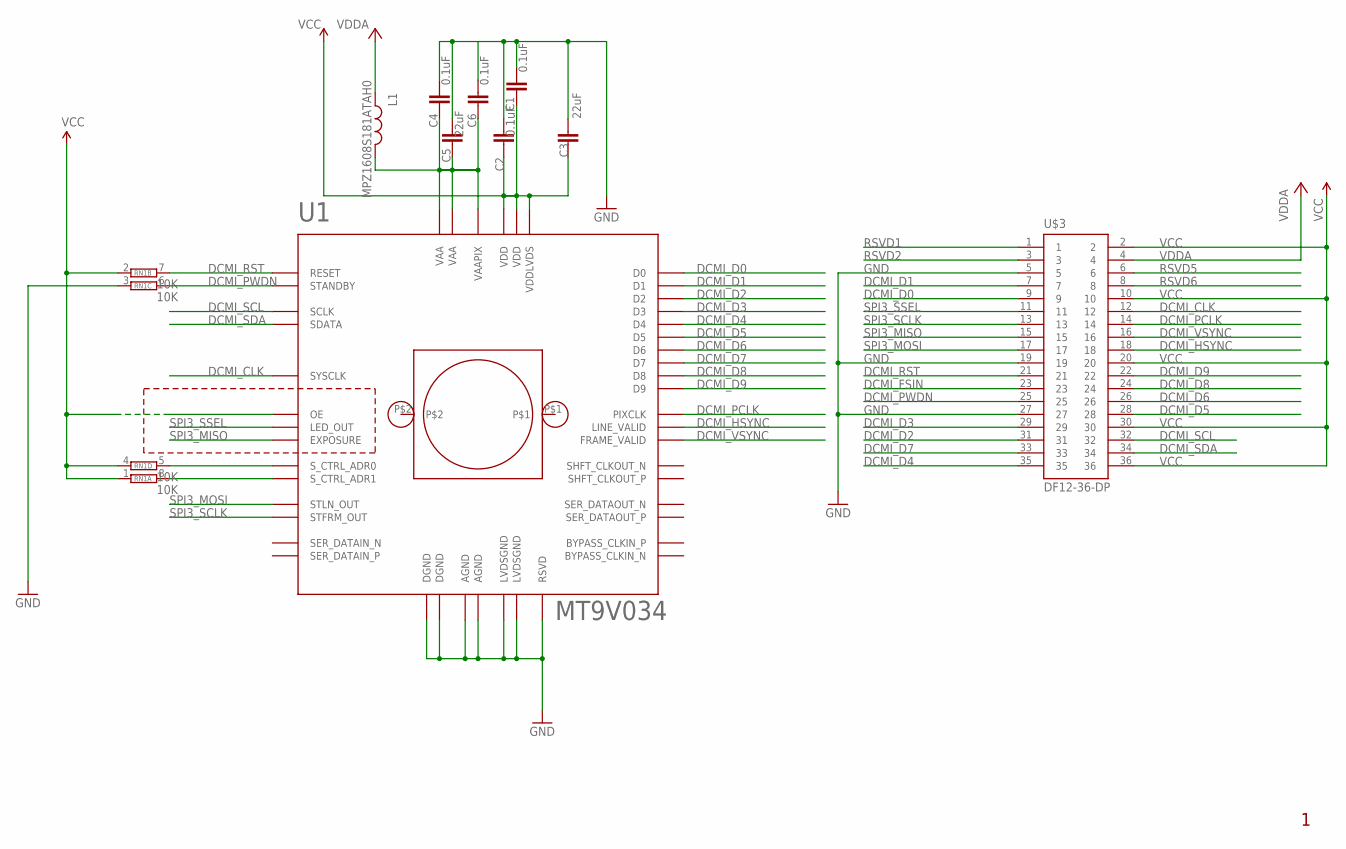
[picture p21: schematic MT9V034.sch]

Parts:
C1, C2, C4, C6: 0.1uF; 0402-CAP
C3, C5: 22uF; 0805
L1: MPZ1608S181ATAH0; 0603
LM1: LENSMOUNT20MM; LENSMOUNT-20MM
RN1: 10K; EXBV8V
U1: MT9V034; CLCC-48
U$3: DF12-36-DP

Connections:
DCMI_CLK: U1.P$47 (SYSCLK), U$3.12
DCMI_D0: U1.P$45 (D0), U$3.9
DCMI_D1: U1.P$44 (D1), U$3.7
DCMI_D2: U1.P$43 (D2), U$3.31
DCMI_D3: U1.P$42 (D3), U$3.29
DCMI_D4: U1.P$41 (D4), U$3.35
DCMI_D5: U1.P$15 (D5), U$3.28
DCMI_D6: U1.P$16 (D6), U$3.26
DCMI_D7: U1.P$17 (D7), U$3.33
DCMI_D8: U1.P$18 (D8), U$3.24
DCMI_D9: U1.P$19 (D9), U$3.22
DCMI_FSIN: U$3.23
DCMI_HSYNC: U1.P$20 (LINE_VALID), U$3.18
DCMI_PCLK: U1.P$46 (PIXCLK), U$3.14
DCMI_PWDN: RN1.6 (2), U1.P$33 (STANDBY), U$3.25
DCMI_RST: RN1.7 (2), U1.P$32 (RESET), U$3.21
DCMI_SCL: U1.P$25 (SCLK), U$3.32
DCMI_SDA: U1.P$24 (SDATA), U$3.34
DCMI_VSYNC: U1.P$21 (FRAME_VALID), U$3.16
GND: C1.2, C2.2, C3.1, C4.2, C5.1, C6.2, RN1.3 (1), U1.P$7 (LVDSGND), U1.P$12 (LVDSGND), U1.P$13 (DGND), U1.P$29 (RSVD), U1.P$34 (AGND), U1.P$38 (AGND), U1.P$48 (DGND), U$3.5, U$3.19, U$3.27
unnamed: RN1.5 (2), U1.P$30 (S_CTRL_ADR0)
unnamed: RN1.8 (2), U1.P$31 (S_CTRL_ADR1)
RSVD1: U$3.1
RSVD2: U$3.3
RSVD5: U$3.6
RSVD6: U$3.8
SPI3_MISO: U1.P$23 (EXPOSURE), U$3.15
SPI3_MOSI: U1.P$22 (STLN_OUT), U$3.17
SPI3_SCLK: U1.P$26 (STFRM_OUT), U$3.13
SPI3_SSEL: U1.P$27 (LED_OUT), U$3.11
VAA: C4.1, C5.2, C6.1, L1.2, U1.P$35 (VAA), U1.P$39 (VAA), U1.P$40 (VAAPIX)
VCC: C1.1, C2.1, C3.2, RN1.1, RN1.2 (1), RN1.4 (1), U1.P$1 (VDD), U1.P$6 (VDDLVDS), U1.P$14 (VDD), U1.P$28 (OE), U$3.2, U$3.10, U$3.20, U$3.30, U$3.36
VDDA: L1.1, U$3.4

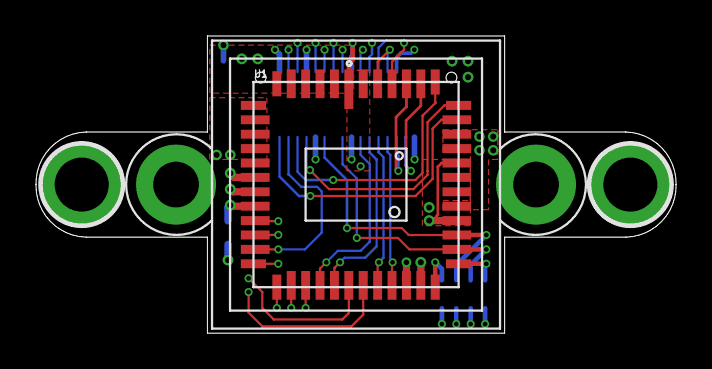
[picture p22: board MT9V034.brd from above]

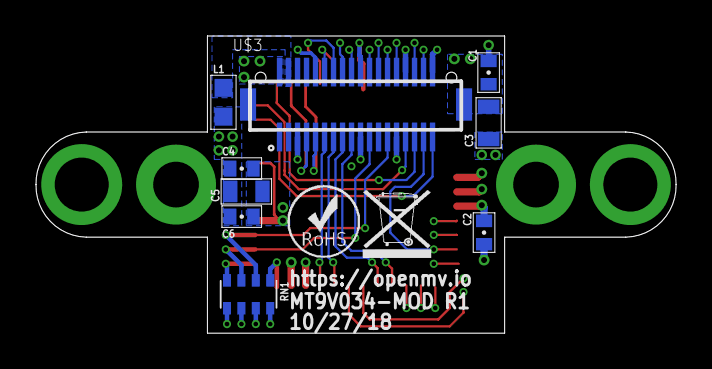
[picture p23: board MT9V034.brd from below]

Board: 4 copper layers, 35.6 x 16.5 mm, 13 parts (11 on the bottom side), 28 nets.

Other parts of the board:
U$1: WEEE
U$2: ROHS

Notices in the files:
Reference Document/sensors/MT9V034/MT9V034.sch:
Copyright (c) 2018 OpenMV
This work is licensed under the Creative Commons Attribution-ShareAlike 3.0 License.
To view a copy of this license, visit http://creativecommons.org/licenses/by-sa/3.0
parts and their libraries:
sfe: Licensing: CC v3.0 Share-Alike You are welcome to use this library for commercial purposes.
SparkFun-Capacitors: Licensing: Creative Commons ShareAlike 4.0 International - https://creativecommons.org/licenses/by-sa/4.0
